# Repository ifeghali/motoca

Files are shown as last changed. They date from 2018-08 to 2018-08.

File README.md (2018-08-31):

# motoca
Arduino open source project for battery operated electric bike improvement. 

Features include:
- startup sound
- parking sensor
- police siren
- horn (or ability to play other sound effects/music)
- led stripe for "fast and furious" mode

Powertrain (motor and led stripe) powered by a 2S LiFe battery (or any other ~6V source like a Pb battery).
Electronics powered by 2S LiPo battery (or any other power source in the range of the regulator) and a 5V regulator.

Video available at https://youtu.be/hqM8O6VFWt4

For further instructions https://www.hackster.io/ifeghali/electric-bike-61835d

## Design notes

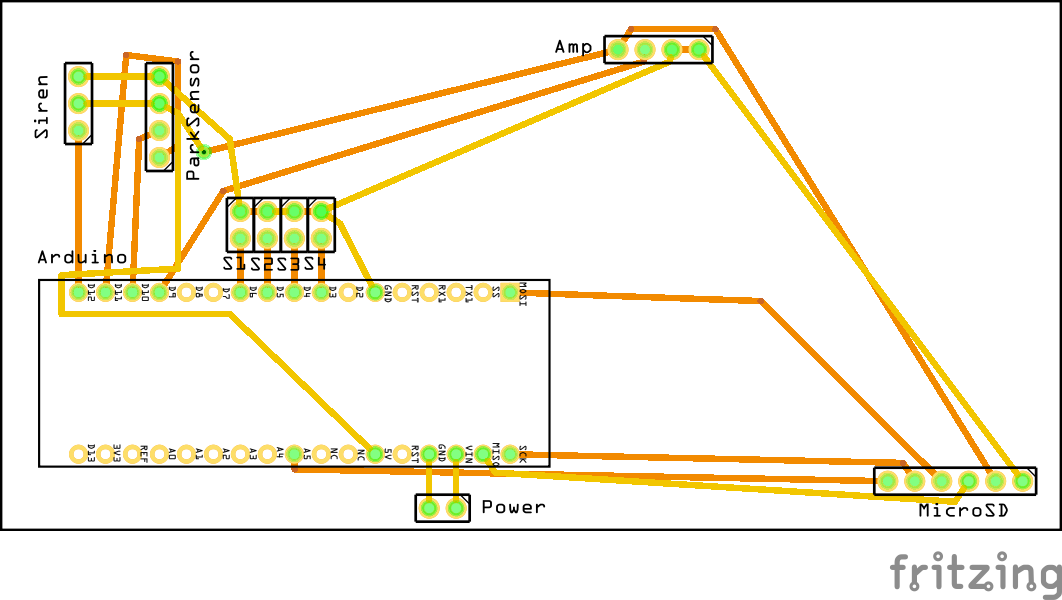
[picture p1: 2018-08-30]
fritzing/motoca_pcb.png

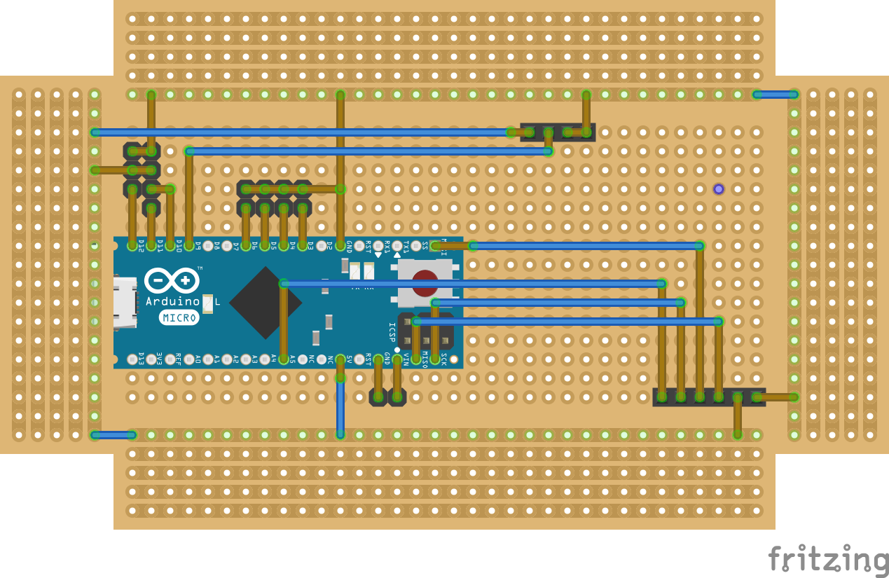
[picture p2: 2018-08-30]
fritzing/motoca_bb.png

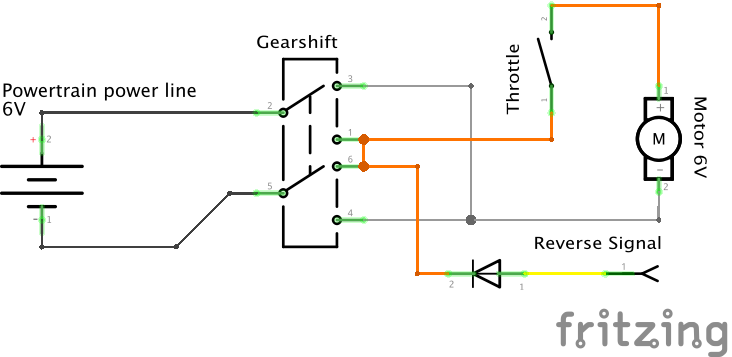
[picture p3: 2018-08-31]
fritzing/powertrain.png

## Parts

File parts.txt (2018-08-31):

Motor Heat Sink w/Fan Red Aluminum (27mm)
https://hobbyking.com/en_us/motor-heat-sink-w-fan-red-aluminum-27mm.html
$5.06

Female XT60 Connectors (5pcs/bag) GENUINE
https://hobbyking.com/en_us/female-xt60-connectors-5pcs-bag-genuine.html
$2.97

Male XT60 Connectors (5pcs/bag) GENUINE
https://hobbyking.com/en_us/male-xt60-connectors-5pcs-bag-genuine.html
$2.06

Turnigy High Quality 24AWG Silicone Wire 1m (Black)
https://hobbyking.com/en_us/turnigy-high-quality-24awg-silicone-wire-1m-black.html
$0.55

Wire Mesh Guard Black 6mm (5m)
https://hobbyking.com/en_us/wire-mesh-guard-black-6mm-5m.html
$2.33

Turnigy 3 Function Switch w/UBEC, Voltage Display
https://hobbyking.com/en_us/turnigy-3-function-switch-w-ubec-voltage-display.html
$10.58

Female JST Battery Pigtail 10cm Length (10pcs/bag)
https://hobbyking.com/en_us/female-jst-battery-pigtail-10cm-length-10pcs-bag.html
$1.97

Male JST Battery Pigtail 12cm Length (10pcs/bag)
https://hobbyking.com/en_us/male-jst-battery-pigtail-12cm-length-10pcs-bag.html
$1.97

LED Strip with JST Female Connector 200mm (Red)
https://hobbyking.com/en_us/led-red-lights-strip-with-jst-connector-200mm.html
$2.11

Round 2-Way Switch (Short) (2pcs)
https://hobbyking.com/en_us/round-2-way-switch-short-2pcs.html
$3.12

Police Car LED Lighting System Squared Style (Blue / Red)
https://hobbyking.com/en_us/police-car-led-lighting-system-squared-style-blue-red.html
$8.27

JST-SH Servo Plug Set (JR) Gold Plated (10pairs/set)
https://hobbyking.com/en_us/jst-sh-servo-plug-set-jr-gold-plated-10pairs-set.html
$2.17

Arduino Micro with Headers A000053 - Mini Controller 5V 16 MHz ATmega32u4
http://a.co/d/hSJfaMl
$17.99

Gikfun HC-SR04 Distance Measuring Transducer Sensor for Arduino EK1084
http://a.co/d/9hYdiHJ
$7.98

Gikfun 20 Times LM386 Audio Amplifier Module with 10K Resistance EK1235
http://a.co/d/6uYlCDl
$6.68

Gikfun SD Storage Board TF Card Memory Shield Module For Arduino EK1442
http://a.co/d/1JVPHHX
$7.68

Gikfun 12mm 250V 3A Push Button Switch PBS-11B No Self-Lock ON/OFF Lock for Arduino (Pack of 10pcs) AE1122
http://a.co/d/dDobr7i
$7.98

uxcell DPDT 6 Terminal 2 Position Boat Rocker Switch Black AC 20A/125V 22A/250V
http://a.co/d/2EZbTZB
$6.02

Hilitchi 10ft/3m 20 Wire Rainbow Color Flat Ribbon IDC Wire Cable
http://a.co/d/eVzXGN9
$6.99

StarTech.com Micro USB Cable - A to Right Angle Micro B (UUSBHAUB3RA), Black, 3 ft/91cm
http://a.co/d/e0Lvi9y
$3.79

Conwork 10-Pack USB 2.0 Type A Female Socket 4 Pin Plug Connector with Black Plastic Cover
http://a.co/d/0JXuBJO
$6.99

10 Pcs 1x40 Pin 2.54mm Pitch Straight Single Row PCB Female Headers
http://a.co/d/5Jv6QT4
$4.98

UPGRADE INDUSTRIES [10x] 1x40 Pin 2.54 mm Right Angle Single Row Female Header Socket - 90 degrees by UPGRADE INDUSTRIES
http://a.co/d/hTWqy2d
$14.77

|-------------------------------------------------------------------------------
|Gikfun 1 X 40pin 2.54 breakaway Male header for Arduino (Pack of 20pcs) EK1017
|http://a.co/d/24iU2xD
|$7.88
|
|1 Pin Dupont Connector (5set/bag)
|https://hobbyking.com/en_us/jwt-connectors-1-pin-5set-bag.html
|$0.50
|
|2 Pin Dupont Connector (5set/bag)
|https://hobbyking.com/en_us/jwt-connectors-2-pin-5set-bag.html
|$0.92
|
|3 Pin Dupont Connector
|
|4 Pin Dupont Connector (5set/bag)
|https://hobbyking.com/en_us/jwt-connectors-4-pin-5set-bag.html
|$1.58
|-OR THE KIT--------------------------------------------------------------------
|Hilitchi 635 Pcs 40 Pin 2.54mm Pitch Single Row Pin Headers,Dupont Connector Housing Female,Dupont Male/Female Pin Connector Kit
|http://a.co/d/ha07HEC
|$10.99
|-------------------------------------------------------------------------------

50 Pcs Female Wire Crimp Spade Terminals Quick Disconnect Electric Connectors 15A 1.5-2.5mm²
http://a.co/d/deb2hhV
$1.02

10x5cm Veroboard

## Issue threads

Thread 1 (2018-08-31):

siren makes noise in speaker

ifeghali, 2018-08-31:
Rewire amp’s ground to mitigate noise from siren

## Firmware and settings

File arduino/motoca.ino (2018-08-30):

/**
 * Arduino open source project for battery operated electric bike
 * 
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
 * Author: Igor Feghali <ifeghali@php.net>
 *
 */
 
#define DISABLE_SPEAKER2
//#define DEBUG

#include <SD.h>
#include <TMRpcm.h>
#include <SPI.h>

#define PIN_SDCARD A5
#define PIN_SW_GIROFLEX 3       // a
#define PIN_SW_REVERSE 4        // b
#define PIN_SW_SIREN 5          // c
#define PIN_SW_HONK 6           // d
#define PIN_SPEAKER 9           // DON'T TOUCH
#define PIN_SENSOR_ECHO 10
#define PIN_SENSOR_TRIGGER 11
#define PIN_GIROFLEX 12

#ifdef DEBUG
#define DPRINT(x) Serial.print(x)
#define DPRINTLN(x) Serial.println(x)
#else
#define DPRINT(x)
#define DPRINTLN(x)
#endif

TMRpcm audio;   // create an object for use in this sketch
int giroflex_mode = 0;
int last_state = -1;
int count_siren = 0;

void setup() {
  pinMode(PIN_SW_GIROFLEX, INPUT_PULLUP);
  pinMode(PIN_SW_REVERSE, INPUT_PULLUP);
  pinMode(PIN_SW_SIREN, INPUT_PULLUP);
  pinMode(PIN_SW_HONK, INPUT_PULLUP);
  pinMode(PIN_SENSOR_ECHO, INPUT);
  pinMode(PIN_SENSOR_TRIGGER, OUTPUT);
  digitalWrite(PIN_SENSOR_TRIGGER, LOW);
  pinMode(PIN_GIROFLEX, OUTPUT);
  digitalWrite(PIN_GIROFLEX, LOW);
  pinMode(PIN_SPEAKER, OUTPUT);
  pinMode(PIN_SDCARD, OUTPUT);

#ifdef DEBUG
  Serial.begin(9600);
  while (!Serial) {
    ; // wait for serial port to connect. Needed for Arduino Micro
  }
#endif

  audio.speakerPin = PIN_SPEAKER;
  audio.setVolume(4);
  if (!SD.begin(PIN_SDCARD)) {
    DPRINTLN("SD fail");
    tone(PIN_SPEAKER, 392);
    delay(250);
    tone(PIN_SPEAKER, 262);
    delay(500);
    noTone(PIN_SPEAKER);
  } else {
    audio.play("start.wav");
    while (audio.isPlaying());
    audio.disable();
  }
  DPRINTLN("done setup");
}

void loop() {
  int state = 0;
  state += debounce(PIN_SW_GIROFLEX) << 3;
  state += debounce(PIN_SW_REVERSE)  << 2;
  state += debounce(PIN_SW_SIREN)    << 1;
  state += debounce(PIN_SW_HONK);

  if (last_state != state) {
    DPRINT("state: ");
    DPRINTLN(state);
  }
  last_state = state;

  switch (state) {
    case B0000:
      giroflex(0);
      reset_siren();
      audio.disable();
      noTone(PIN_SPEAKER);
      break;
    case B0011:
    case B0010:
    case B1010:
      if (count_siren < 10) {
        count_siren++;
        DPRINT("siren button hold :");
        DPRINTLN(count_siren);
      } else {
        giroflex(2);
        if (!audio.isPlaying())
          audio.play("s2.wav");
      }
      break;
    case B0101:
    case B0100:
    case B0110:
    case B0111:
      giroflex(0);
    case B1100:
    case B1101:
    case B1110:
    case B1111:
      count_siren = 0;
      audio.disable();
      parking();
      break;
    case B1000:
      reset_siren();
      audio.disable();
      noTone(PIN_SPEAKER);
      giroflex(5);
      break;
    case B0001:
      giroflex(0);
      reset_siren();
      if (!audio.isPlaying()) {
        audio.play("honk.wav");
        while (audio.isPlaying());
      }
      break;
    case B1001:
      reset_siren();
    case B1011:
      giroflex(5);
      if (!audio.isPlaying()) {
        audio.play("honk.wav");
        while (audio.isPlaying());
      }
      break;
  }
}

void reset_siren() {
  if (count_siren > 0 and count_siren < 10) {
    giroflex(3);
    audio.disable();
    audio.play("s1.wav");
    while (audio.isPlaying());
    giroflex(0);
  }
  count_siren = 0;
}

void parking() {
  DPRINTLN("parking");
  pinMode(PIN_SPEAKER, OUTPUT);
  noTone(PIN_SPEAKER);
  tone(PIN_SPEAKER, 440, 100);
  delay(500);

  while (digitalRead(PIN_SW_REVERSE) == LOW) {
    digitalWrite(PIN_SENSOR_TRIGGER, HIGH);
    delayMicroseconds(5);
    digitalWrite(PIN_SENSOR_TRIGGER, LOW);
    unsigned long int tt = pulseIn(PIN_SENSOR_ECHO, HIGH);
    if (tt > 2000) {
      noTone(PIN_SPEAKER);
      continue;
    }
    tt = (tt <  500) ? 500  : tt;
    int d = map(tt, 2000, 500, 500, 0);
    tone(PIN_SPEAKER, 440, 100);
    delay(d);
  }

  noTone(PIN_SPEAKER);
  DPRINTLN("no parking");
}

int debounce(int but) {
  int count = 0;
  do {
    delay(1);
    count++;
    if (count >= 50) {
      return 1;
    }
  } while (digitalRead(but) == LOW);
  return 0;
}

void giroflex(int target_mode) {
  /**
     MODE 0: OFF
     MODE 1: LEFT/RIGHT
     MODE 2: LEFT/RIGHT QUICKLY
     MODE 3: ALL FLASH
     MODE 4: BACK/FORTH
     MODE 5: BACK/FORTH QUICKLY
     MODE 6: MIXED
  */

  if (giroflex_mode == target_mode)
    return;

  DPRINT("giroflex mode ");
  DPRINTLN(target_mode);

  /*
   * audio can mess with timers so we wait for it to finish
   */
  while (audio.isPlaying());

  int i;
  for (i = giroflex_mode; i != target_mode; i = (i + 1) % 7) {
    digitalWrite(PIN_GIROFLEX, HIGH);
    delayMicroseconds(900);
    digitalWrite(PIN_GIROFLEX, LOW);
    delay(2);
    digitalWrite(PIN_GIROFLEX, HIGH);
    delayMicroseconds(2000);
    digitalWrite(PIN_GIROFLEX, LOW);
    delay(2);
    digitalWrite(PIN_GIROFLEX, HIGH);
    delayMicroseconds(900);
    digitalWrite(PIN_GIROFLEX, LOW);
    delay(2);
    digitalWrite(PIN_GIROFLEX, HIGH);
    delayMicroseconds(2000);
    digitalWrite(PIN_GIROFLEX, LOW);
    delay(2);
  }
  giroflex_mode = i;
}

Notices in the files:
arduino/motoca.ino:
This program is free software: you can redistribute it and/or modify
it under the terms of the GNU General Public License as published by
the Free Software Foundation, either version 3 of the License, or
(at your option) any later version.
